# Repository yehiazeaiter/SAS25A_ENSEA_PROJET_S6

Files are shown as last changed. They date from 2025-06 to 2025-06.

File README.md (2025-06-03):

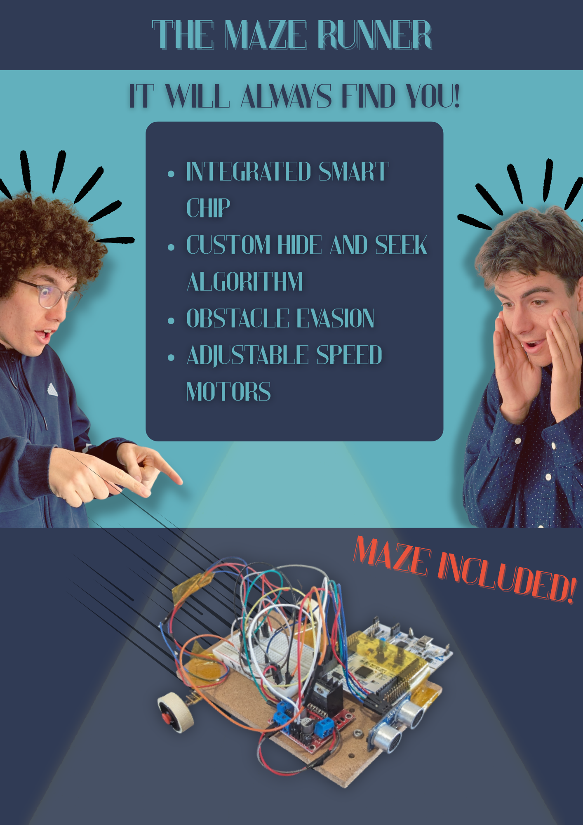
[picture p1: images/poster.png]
Project Poster


# SAS25A_ENSEA_PROJET_S6

This repository contains the code and documentation for our first year school project. An embedded systems project using STM32CubeIDE to build a robot that plays hide and seek in a labyrinth using motors for moving, an ultrasonic sensor for obstacle detection, and an infrared sensor for detecting the other playing robot.

## Table of Contents
- [Project Overview](#project-overview)
- [Team Members](#team-members)
- [Folder Structure](#folder-structure)

## Project Overview

This embedded systems project aimed to build a robot capable of playing a game of hide-and-seek using sensors and motor control, based on the STM32L476RG microcontroller, in a compact design with an integrated PCB.

### What We Achieved
- The robot can **move forward** using DC motors
- It **stops automatically** when an obstacle is detected via the ultrasonic sensor
- It **blinks an LED** when receiving a signal from the infrared receiver
- A PCB design ready to print

### What Was Not Fully Implemented
- Autonomous hide-and-seek behavior
- Navigation or decision-making logic
- Compact design with an integrated PCB

Despite not reaching the original goal, the project successfully integrates core embedded system concepts such as motor control, sensor interfacing, and interrupt-based signaling.

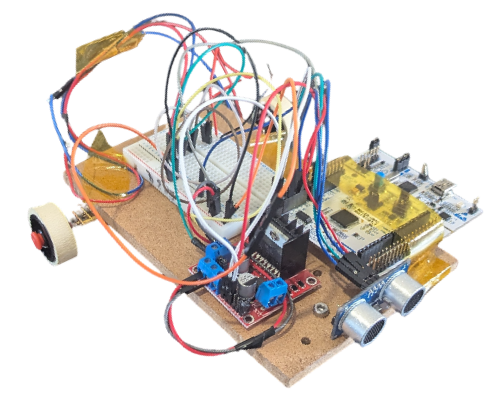
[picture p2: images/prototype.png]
Project Prototype


## Team Members

- BELLAHBIB Amate-Allah 
- EL MESTARI Mohamed-Amine 
- NASSCHAERT Florent 
- PERRIN Maël 
- ZEAITER Yehia 

### Contributions

| Member | Contributions Summary | 
|---|---|
| Amate-Allah  | PCB design, infrared sensor testing, final presentation, final report |
| Mohamed-Amine| Ultrasonic sensor testing, weekly reports, final report |
| Florent | Infrared sensor testing, programming, timer setup, algorithm diagram |
| Maël | Stepper motors testing, 3D modeling, GANTT diagram |
| Yehia | Ultrasonic sensor testing, DC and stepper motors testing, timer setup, SADT diagram, task distribution  |

## Folder structure
- `project files/`: KiCad and STM32CubeIDE project files
- `how to guides/`: guides on how to achieve the different tasks done in the project

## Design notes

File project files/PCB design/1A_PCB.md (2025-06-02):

## This folder contains all the files related to the PCB design

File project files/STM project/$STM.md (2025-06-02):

## This folder contains the STM project that was used to run the prototype

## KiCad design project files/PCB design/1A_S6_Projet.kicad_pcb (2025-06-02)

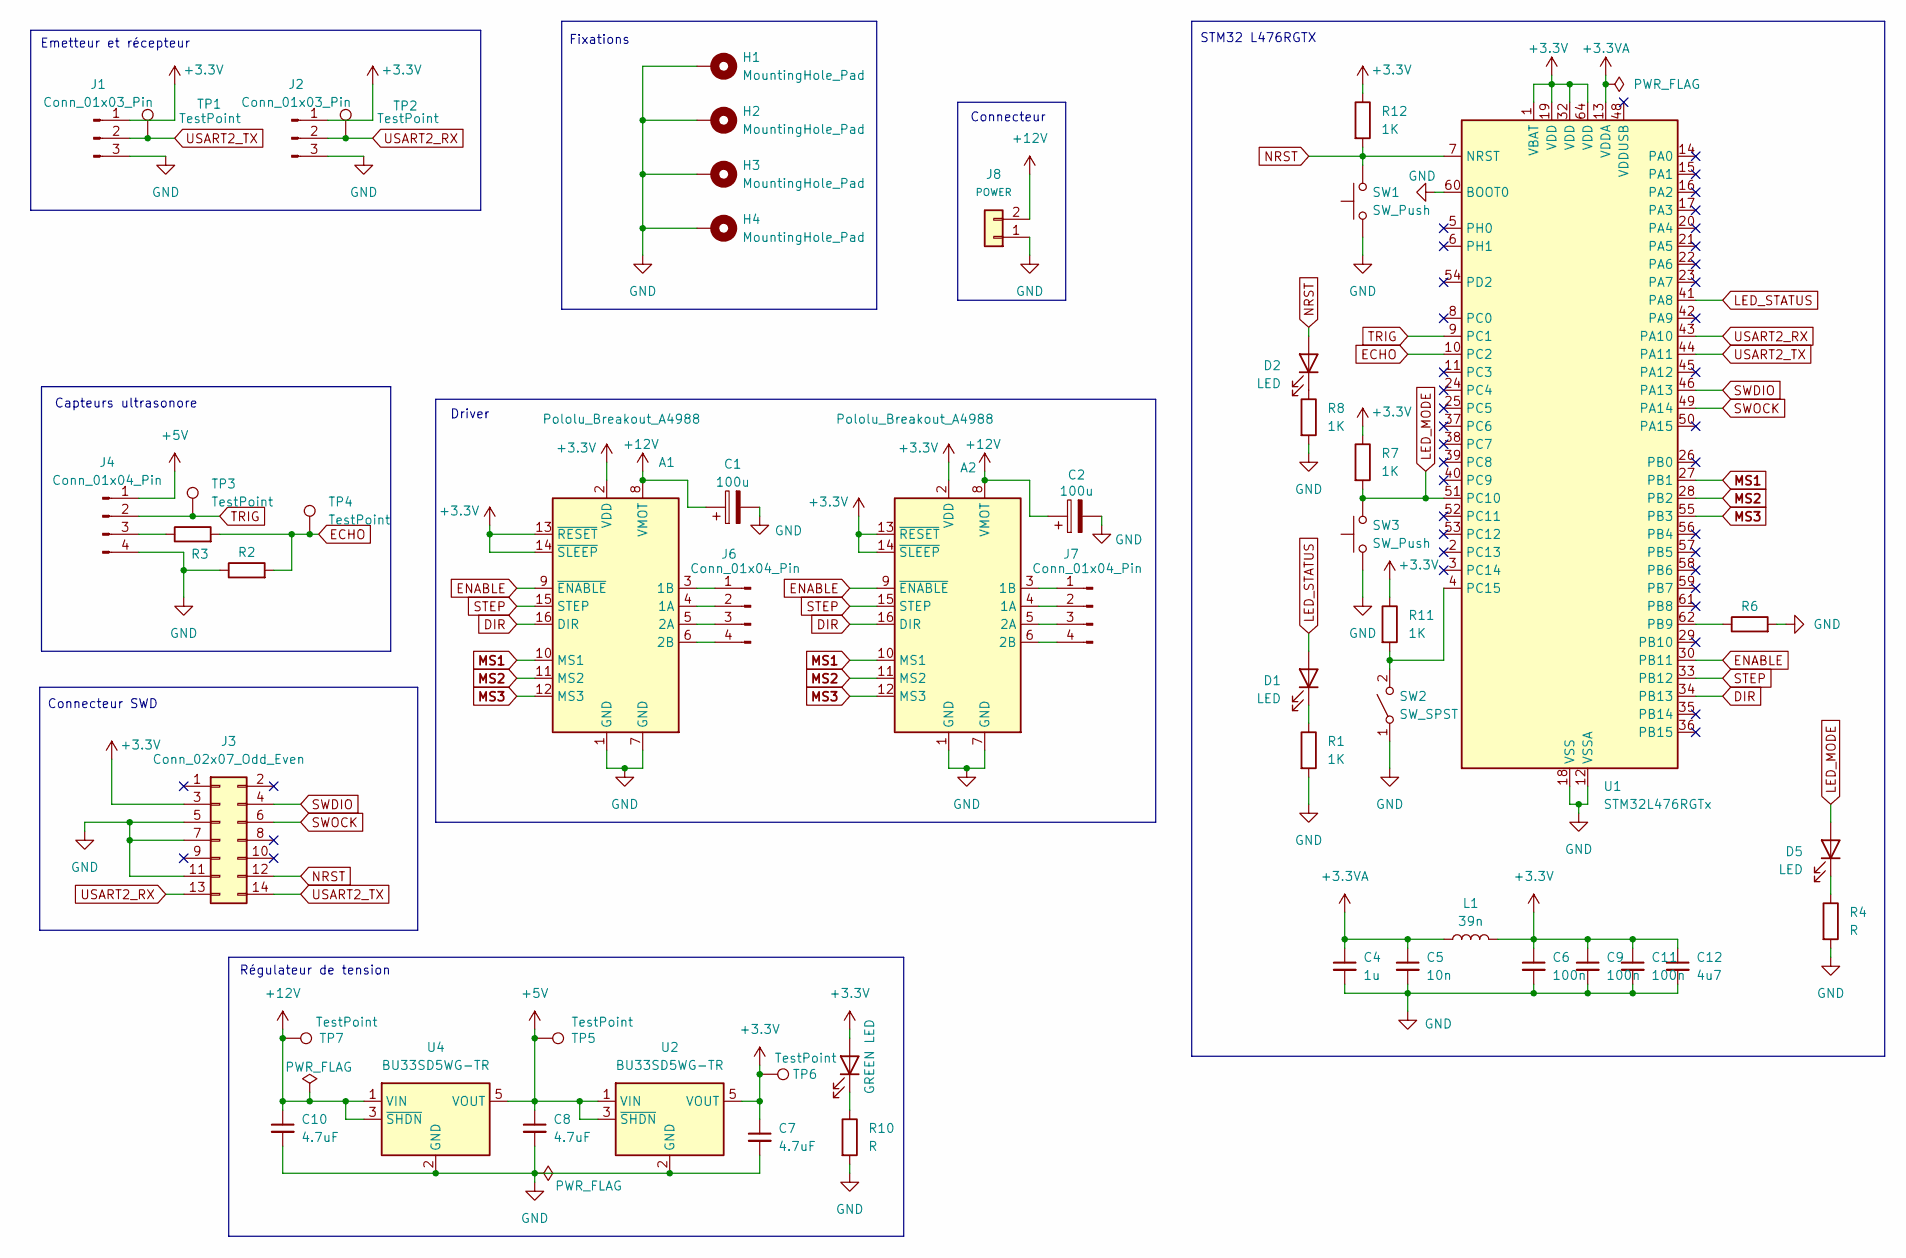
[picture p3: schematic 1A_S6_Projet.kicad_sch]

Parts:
A1, A2: Pololu_Breakout_A4988; Pololu_Breakout-16_15.2x20.3mm
C1, C2: 100u; CP_Elec_8x10.5
C4: 1u; C_1206_3216Metric_Pad1.33x1.80mm_HandSolder
C5: 10n; C_0805_2012Metric_Pad1.18x1.45mm_HandSolder
C6, C9, C11: 100n; C_1206_3216Metric_Pad1.33x1.80mm_HandSolder
C7, C8, C10: 4.7uF; C_1206_3216Metric_Pad1.33x1.80mm_HandSolder
C12: 4u7; C_1206_3216Metric_Pad1.33x1.80mm_HandSolder
D1, D2, D5: LED; LED_0603_1608Metric_Pad1.05x0.95mm_HandSolder
D4: GREEN LED; LED_0603_1608Metric_Pad1.05x0.95mm_HandSolder
H1, H2, H3, H4: MountingHole_Pad; MountingHole_3.2mm_M3_DIN965_Pad
J1, J2: Conn_01x03_Pin; JST_XH_B3B-XH-A_1x03_P2.50mm_Vertical
J3: Conn_02x07_Odd_Even; PinHeader_2x07_P1.27mm_Vertical_SMD
J4, J6, J7: Conn_01x04_Pin; JST_XH_B4B-XH-A_1x04_P2.50mm_Vertical
J8: POWER; JST_XH_B2B-XH-A_1x02_P2.50mm_Vertical
L1: 39n; L_0805_2012Metric_Pad1.05x1.20mm_HandSolder
R1, R3, R6, R7, R8, R11, R12: 1K; R_0603_1608Metric_Pad0.98x0.95mm_HandSolder
R2: 2K; R_0603_1608Metric_Pad0.98x0.95mm_HandSolder
R4, R10: R; R_0603_1608Metric_Pad0.98x0.95mm_HandSolder
SW1, SW3: SW_Push; SW_Push_1P1T_NO_CK_KMR2
SW2: SW_SPST; SW_Push_1P1T_NO_CK_KMR2
TP1, TP2, TP3, TP4, TP5, TP6, TP7: TestPoint; TestPoint_Pad_D1.0mm
U1: STM32L476RGTx; LQFP-64_10x10mm_P0.5mm
U2, U4: BU33SD5WG-TR; SOT-23-5

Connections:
+3.3V: A1.2 (VDD), A1.13 (~RESET), A1.14 (~SLEEP), A2.2 (VDD), A2.13 (~RESET), A2.14 (~SLEEP), C6.1, C7.1, C9.1, C11.1, C12.1, D4.2 (A), J1.1, J2.1, J3.3, L1.2, R7.1, R11.1, R12.1, TP6.1, U1.1 (VBAT), U1.19 (VDD), U1.32 (VDD), U1.64 (VDD), U2.5 (VOUT)
+3.3VA: C4.1, C5.1, L1.1, U1.13 (VDDA)
+5V: C8.1, J4.1, TP5.1, U2.1 (VIN), U2.3 (~SHDN), U4.5 (VOUT)
+12V: A1.8 (VMOT), A2.8 (VMOT), C1.1, C2.1, C10.1, J8.2, TP7.1, U4.1 (VIN), U4.3 (~SHDN)
DIR: A1.16 (DIR), A2.16 (DIR), U1.34 (PB13)
ECHO: R2.2, R3.2, TP4.1, U1.10 (PC2)
ENABLE: A1.9 (~ENABLE), A2.9 (~ENABLE), U1.30 (PB11)
GND: A1.1 (GND), A1.7 (GND), A2.1 (GND), A2.7 (GND), C1.2, C2.2, C4.2, C5.2, C6.2, C7.2, C8.2, C9.2, C10.2, C11.2, C12.2, H1.1, H2.1, H3.1, H4.1, J1.3, J2.3, J3.5, J3.7, J3.11, J4.4, J8.1, R1.2, R2.1, R4.2, R6.2, R8.2, R10.2, SW1.1, SW2.1 (A), SW3.1, U1.12 (VSSA), U1.18 (VSS), U1.31 (VSS), U1.47 (VSS), U1.60 (BOOT0), U1.63 (VSS), U2.2 (GND), U4.2 (GND)
LED_MODE: D5.2 (A), R7.2, SW3.2, U1.51 (PC10)
LED_STATUS: D1.2 (A), U1.41 (PA8)
MS1: A1.10 (MS1), A2.10 (MS1), U1.27 (PB1)
MS2: A1.11 (MS2), A2.11 (MS2), U1.28 (PB2)
MS3: A1.12 (MS3), A2.12 (MS3), U1.55 (PB3)
NRST: D2.2 (A), J3.12, R12.2, SW1.2, U1.7 (NRST)
unnamed: A1.4 (1A), J6.2
unnamed: A1.3 (1B), J6.1
unnamed: A1.5 (2A), J6.3
unnamed: A1.6 (2B), J6.4
unnamed: A2.4 (1A), J7.2
unnamed: A2.3 (1B), J7.1
unnamed: A2.5 (2A), J7.3
unnamed: A2.6 (2B), J7.4
unnamed: D1.1 (K), R1.1
unnamed: D2.1 (K), R8.1
unnamed: D4.1 (K), R10.1
unnamed: D5.1 (K), R4.1
unnamed: J4.3, R3.1
unnamed: R11.2, SW2.2 (B), U1.4 (PC15)
unnamed: R6.1, U1.62 (PB9)
STEP: A1.15 (STEP), A2.15 (STEP), U1.33 (PB12)
SWDIO: J3.4, U1.46 (PA13)
SWOCK: J3.6, U1.49 (PA14)
TRIG: J4.2, TP3.1, U1.9 (PC1)
USART2_RX: J2.2, J3.13, TP2.1, U1.43 (PA10)
USART2_TX: J1.2, J3.14, TP1.1, U1.44 (PA11)

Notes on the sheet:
Capteurs ultrasonore
STM32 L476RGTX
Fixations
Régulateur de tension
Connecteur
Connecteur SWD
Driver
Emetteur et récepteur

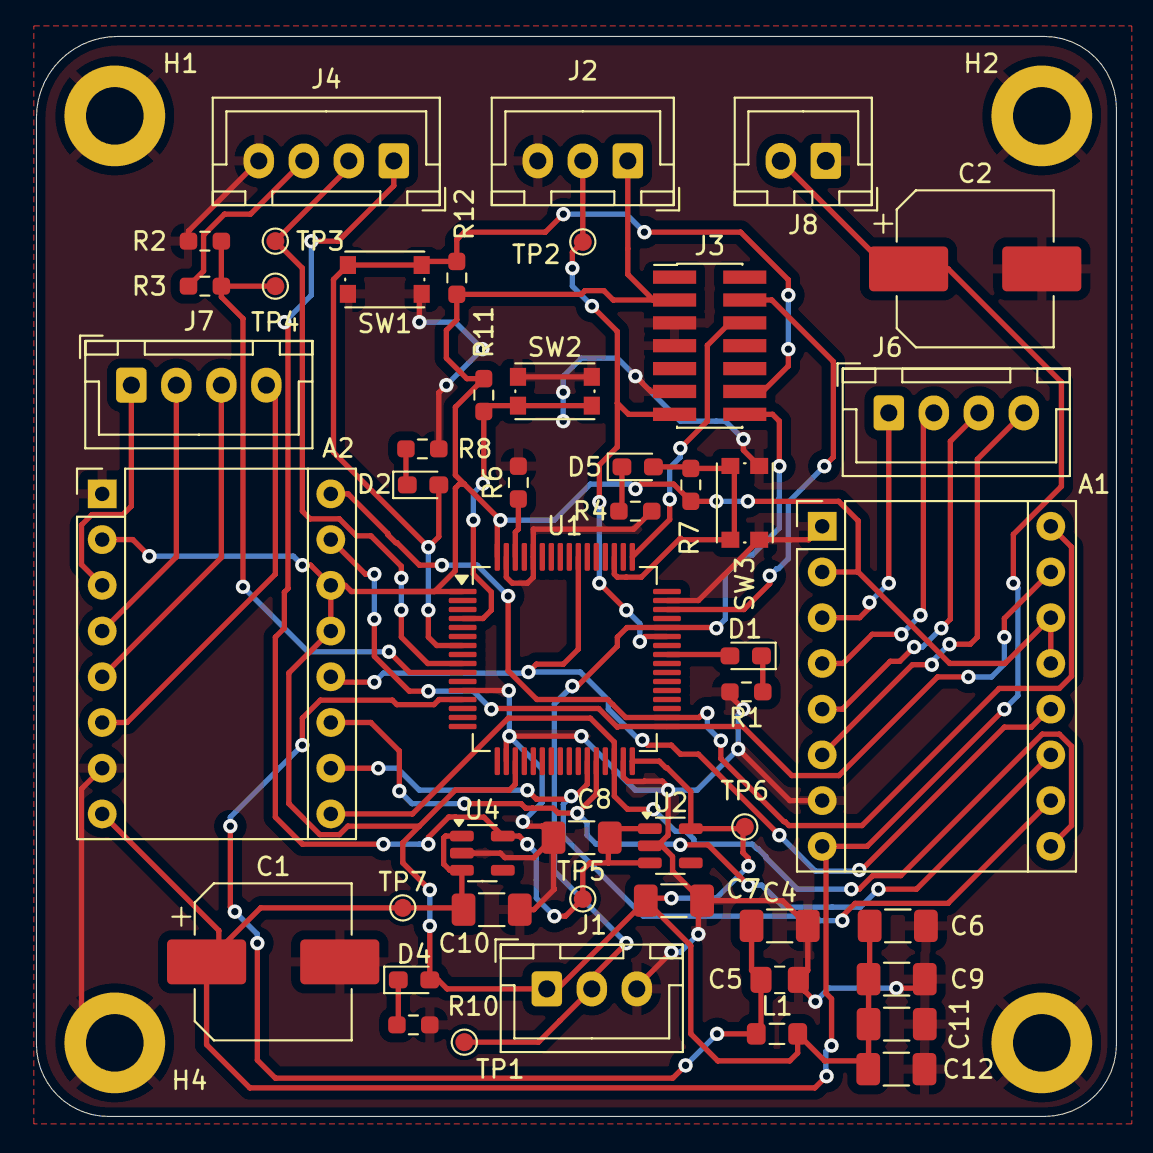
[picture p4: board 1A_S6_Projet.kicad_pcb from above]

Board: 2 copper layers, 60.0 x 60.0 mm, 52 parts (0 on the bottom side), 35 nets.

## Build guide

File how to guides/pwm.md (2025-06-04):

# Quick guide to generate a PWM signal with an ST microcontroller

## What is it? 
PWM stands for Pulse-width modulation, which is any method of representing a signal as a rectangular wave with a varying duty cycle. So a PWM signal is simply a rectengular wave with a varying duty cycle.
PWM signals

*Representation of a PWM signal with different duty cycles*

## Its uses
PWM is mainly used to get **analog like** results with a digital signal, and by digital signal, we mean a signal that switches between two values : 
- LOW which corresponds to 0 V
- HIGH which corresponds to a positive value, commonly 3.3 V or 5 V for microcontrollers

PWM is therefore useful for controlling the average power or or effective voltage delivered by an electrical signal. The higher the duty cycle is, the higher the average is. This is useful in applications like controlling LED brightness, DC motor speed, servo position, heating elements, and more.

The frequency of the signal is also important, it should be chosen correctly so that the electronic device is not negatively affected by the constant ON and OFF switching of the signal.

For example, if you use a PWM signal with a frequency of 10 Hz to control an LED’s brightness, the LED will appear to blink because the human eye can detect such slow flickering. However, if the frequency is increased to 1000 Hz or more, and the duty cycle is 50%, the LED will appear to emit a steady light at reduced brightness due to the eye's persistence of vision.

On the other hand, a motor, being electromechanical, cannot react instantly to rapid changes in the signal, due to inductance and inertia, so when choosing a PWM signal with a high enough frequency, the motor effectively responds to the average power of the PWM signal, rather than each individual pulse. 
Essentially, the frequency should be high enough so that the motor is not able to keep up with the signal fluctuations, otherwise there will be jitters in the movement. 

These two examples were given to explain that we see similar results (smooth output) in different devices, but they're due to different reasons, which is always good to keep in mind.

That being said, a frequency shouldn't be too high for the component either to avoid possible power dissipation and heating problems.
Always refer to the component's datasheet or technical specifications to have the correct frequency range.

## Generating a PWM signal with a microcontroller
For our example, we'll be using STML476RG, but this method shouldn't be very different across different ST microcontrollers.

PWM generation is pretty forward, it is done using timers, in our example, we chose the timer TIM5.
This timer can generate PWM signals in 4 channels, we'll choose channel 2. Do not forget to check the internal clock box.

There are three main parameters affecting our signal, PSC and ARR to choose its frequency, and the Pulse parameter decides the value of the duty cycle.
Our main clock speed is at 80 MHz, we choose PSC = 79 and ARR = 999 to have a timer frequency of 1 kHz.

The Pulse value basically refers the number of timer counts the output stays HIGH within each PWM cycle, therefore, it should be chosen relatively to the ARR value.
For example, to have a 50% duty cycle, we set Pulse to 500.
tim5 settings

*Screenshot of the TIM5 configuration*

As you can see in the parameters, there are different PWM modes to choose from, for a normal PWM signal, we choose Mode 1. It simply means that the output is HIGH when the timer counter is less than the Pulse value, and LOW when it's equal or greater, so the signal starts by being HIGH then switches to LOW.

Now that the timer is set, we can configure different pins to recieve this signal. For example, we choose PA1 :


Save the ioc file so that the IDE apply your configuration. Now you just need to start TIM5 and its PWM generation in the main.c file, in the `main()` function, after the initializations (in the  /* USER CODE BEGIN 2 */ for our case). 
```c
  HAL_TIM_Base_Start_IT(&htim5);
  HAL_TIM_PWM_Start(&htim5, TIM_CHANNEL_2);
```

If you want to change the ARR value (to control the frequency) or the Pulse value (to control the duty cycle) at any moment in the code, you can use the functions `__HAL_TIM_SET_AUTORELOAD(__HANDLE__, __AUTORELOAD__)` and `__HAL_TIM_SET_COMPARE(__HANDLE__, __CHANNEL__, __COMPARE__)`, in our case, the syntax would be :
```c
__HAL_TIM_SET_AUTORELOAD(&htim5, new_arr);               //used to change the ARR value
__HAL_TIM_SET_COMPARE(&htim5, TIM_CHANNEL_2, new_pulse); //used to change the Pulse value
```
And that's it!

Now you can visualise this signal on an oscilloscope, or try to dynamically change the brightness of a LED if you want a first easy application.
Enjoy!

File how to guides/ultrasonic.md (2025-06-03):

# Guide to setup and use the ultrasonic sensor HC-SR04 with STM32CubeIDE

## What it is for
This module is used to measure distances between 3 cm and 2 meters (otherwise it loses accuracy)

## Constitution
The HC-SR04 ultrasonic module is equiped with two main parts, an ultrasonic transmitter, and an ultrasonic receiver. It contains 4 pins : 
- 5V pin to power the module
- Trigger pin to control the transmitter
- Echo pin to read the receiver
- GND pin

Ultrasonic sensor

## How it works
The ultrasonic transmitter sends periodic 8 cycle bursts of ultrasound at 40 kHz with boosted echo. Upon detecting an object, these waves are reflected towards the receiver. Therefore, the time it takes for these waves to travel to the object forth and back is used to calculate the distance.

Ultrasonic waves

*Image credit : teachwithict*

## Visualization 
In order to write the necessary STM code to correctly use this module, we have to understand what we should code precisely.
There are mainly two things :
- Pulse generation with the transmitter
- Reading the echoed signal with the receiver

According to the datasheet, the trigger needs to be supplied by 10 μs pulses and then the transmitter will send out
an 8 cycle burst of ultrasound at 40 kHz and raise its echo. The pulses sent to the Trigger pin should look like this:

pulses

zoomed in pulse

The signal read on the Echo pin looks like the following :

echo

In fact, the Echo signal stays on HIGH level until it receives the ultrasonic wave echo. Therefore, in order to calculate distance with its input, we should calculate the distance an ultrasonic wave travels during the time where it stays high, divided by two, because the wave travels the distance to the object back and forth.

In the following sections, we'll see how to do the right setup to finally calculate distance.

## Pin setup
- 5V pin should be connected to a 5V power supply (can be drawn from the STM)
- Trigger pin should be connected to the STM in GPIO Output mode
- Echo pin should be connected to the STM in GPIO_EXTI mode (will be explained later)
- The GND pin should be connected to the GND node of the circuit

## Pulse generation
In order to generate pulses, we are going to use some STM timer action. We need pulses with 10 μs width, we'll choose a periodicity of 200 ms in able to safely calculate distances up to 20 meters (you can do the maths yourself!). 
To generate these pulses, we will set a timer that creates interrupts every 10 μs. For our example, we're using an STML476RG microcontroller which has a core clock speed of 80 MHz, we choose to use the timer TIM2 for this mission. Go to the ioc configuration file and set the following values in the TIM2 section :
- Set the Clock Source to Internal Clock
- Set the PSC to 79
- Set the ARR to 9
  
  *These PSC and ARR values are to be adjusted to your core clock speed*

  Save the ioc file and the necessary initialisation code will be generated by the IDE.

TIM2 config

*Screenshot of the timer TIM2 settings*

After setting up the timer, we should enable its interrupts, in the ioc file you go to Pinout&Confiration -> System Core -> NVIC and you check the TIM2 global interrupt box :



*Screenshot of the NVIC settings*

Now that the timer is set up, we can start generating the pulses, a pulse is simply a high level between two interruptions, every 200 ms. 
Therefore, the code is very simple, in the stm32*_it.c file (stm32l4xx_it.c in our example), you should find a function with the `void TIM2_IRQHandler(void)` prototype, this function is called every time the timer creates an interrupt, therefore every 10 μs. In 200 ms, there are 20.000 intervals of 10 μs width, that's why we define a constant called Trigger_Period = 20000.
During the first one of these intervals, we want the signal sent to the Trigger pin to be set as HIGH, during the remaining intervals, we want it set to low, therefore comes the following code : 

```c
  void TIM2_IRQHandler(void)
{
  /* USER CODE BEGIN TIM2_IRQn 0 */
	if (trigger_counter == Trigger_Period - 1){               // Trigger_Period = 20000
			HAL_GPIO_WritePin(Trigger_Port, Trigger_PIN, SET);
	}
	else if (trigger_counter == Trigger_Period){
		HAL_GPIO_WritePin(Trigger_Port, Trigger_PIN, RESET);
		trigger_counter = 0;
	}

	trigger_counter += 1;

  /* USER CODE END TIM2_IRQn 0 */
  HAL_TIM_IRQHandler(&htim2);
  /* USER CODE BEGIN TIM2_IRQn 1 */

  /* USER CODE END TIM2_IRQn 1 */
}
 ```

What's left is to start the timer after its initialization in the main.c file, you simply write HAL_TIM_Base_Start_IT(&htim2); in the USER BEGIN CODE 2 section of the main function.

You can visualise the output of the Trigger pin on the oscilloscope to verify that the pulse generation is correct.

## Distance calculation
The distance calculation is done through the measuring of the time interval between sending the ultrasonic signal and receiving it back. Once the sonic burst is launched from the module, the Echo pin goes to HIGH state, and once it receives the signal back, it goes back to LOW state, as visualised before.
So in order to calculate the distance, we have to detect this HIGH level using our microcontroller. A simple yet effective way to do it, is to detect the rising edge of the signal, and its falling edge, and calculating the time between them.
Fortunately, the ST microcontroller comes with edge detection features. We mentioned earlier that the Echo pin should be configured in EXTI mode, this is because this mode allows the pin to do interruptions when certain events occur, EXTI actually stands for "external interrupt". In our case, we want interrupts to happen when a rising or a falling edge is detected, in order to check time on each of these instances. 
For our example, we configure the ECHO pin in GPIO_EXTI1 mode. Now we should configure the EXTI behavior. 
Go to the ioc file, Pinout&Confiration -> System Core -> GPIO and select the EXTI pin, select the External Interrupt with Rising/Falling edge triger detection option, make sure that the GPIO Pull-up/Pull-down is set to no.

echo pin

*Screenshot of the GPIO settings*

For measuring time, the calssic `HAL_GetTick()` function won't do the trick in our case, because it has a precision of 1 ms, and sounds travel around 35 cm in 1 ms! So it will generate a great imprecision when calculating distances.
Instead, we'll set up a timer for getting the exact time on two instants : rising edge and falling edge.
For our example, we set TIM1 with a high ARR value for high precision, and to have a time interval large enough to cover distances around 20 m, here is our configuration :

timer echo

Now we get to coding, we create two functions, one for handling the rising edge, it simply tracks the moment the rising edge occured, and the other function is for handling the falling edge, it tracks the moment the falling edge occured and it calculates the distance. 
You might have already figured out that the use of the timer can cause the second time to be lower than the first time because of the timer reset, that's why we use the ternary expression displayed in the code, it corrects the time shift. The high ARR value assures that the start time won't need to be shifted by more than one period.

```c
uint32_t time_start = 0;
uint32_t time_end = 0;
float distance_cm = 0.0f;
extern TIM_HandleTypeDef htim1;

// to track instants, we use the counting of timer 1
void handle_rising_edge(void)
{
    time_start = __HAL_TIM_GET_COUNTER(&htim1);   // tracking of the instant of the rising edge
}

void handle_falling_edge(void)
{
    time_end = __HAL_TIM_GET_COUNTER(&htim1);    // tracking of the instant of the falling edge

    uint32_t duration = (time_end >= time_start) ?
                        (time_end - time_start) :
                        ((0xFFFF - time_start) + time_end);  // the ternary expression assuring the right time calculation
    // speed of an ultrasonic wave in the air ≈ 343 m/s = 0.0343 cm/µs
    // the wave travels the distance back and forth - division by 2
    distance_cm = ((float)duration * 0.0343f) / 2.0f;
}
```

Finally these functions should be called upon interruptions, in the `stm32*_it.c` or the `main.c` file, call them in the EXTI Callback function (you may need to define this function by yourself), according to the signal state.

```c
void HAL_GPIO_EXTI_Callback(uint16_t GPIO_Pin) {
	 if (GPIO_Pin == Echo_PIN)
	    {
	        if (HAL_GPIO_ReadPin(Echo_Port, Echo_PIN) == GPIO_PIN_SET)
	        {
	            handle_rising_edge();

	        }

	        else
	        {
	            handle_falling_edge();
	        }
	    }

}
```

## Use 
As you may have noticed, the constantly update variable "distance_cm" is declared as global, therefore you can use it anywhere in the project, you should simply call it in the .c file you're going to use it in, by typing `extern float distance_cm;` .

I suggest you try to apply that by writing a simple code that makes a LED light up when an object is detected at 10 cm.
Otherwise you can try to print the constantly updated values of the distance in a terminal.

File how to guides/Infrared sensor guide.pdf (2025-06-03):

## Guide pas-à-pas pour la communication infrarouge (émetteur et récepteur )

### 1. Objectif du système

La communication infrarouge a pour but d’assurer une liaison simple entre les deux robots. Plus précisément, dans le cadre du jeu de cache-cache, le robot qui se cache utilise un émetteur infrarouge pour diffuser un signal, tandis que le robot chercheur est équipé d’un récepteur infrarouge lui permettant de détecter la présence du robot caché.

### 2. Composants utilisés

Pour établir la communication infrarouge entre les deux robots, nous avons utilisé des modules de la gamme Grove.

Émetteur infrarouge

- Nom du module : Grove – Infrared Emitter v1.2
- Description : Ce module contient une LED infrarouge capable d’émettre un signal infrarouge. Il est conçu pour fonctionner sous une tension de 5V et se commande via une broche numérique du microcontrôleur.
- lien : https://wiki.seeedstudio.com/Grove-Infrared_Emitter/

Récepteur infrarouge

- Nom du module : Grove – Infrared Receiver v1.0
- Description : Ce module est équipé d’un capteur infrarouge capable de détecter un signal IR provenant de l’émetteur. Il délivre un signal logique en sortie, interprétable par le microcontrôleur pour déterminer la réception d’un signal.
- lien : https://wiki.seeedstudio.com/Grove-Infrared_Emitter/

### 3. Branchement utilisé

Émetteur infrarouge

STM32-L476RG | Grove - Infrared Emitter
5V | Red
GND | Black
Not connected | White
D2 | Yellow

Récepteur infrarouge

STM32-L476RG | Grove - Infrared Emitter
5V | Red
GND | Black
Not connected | White
D4 | Yellow

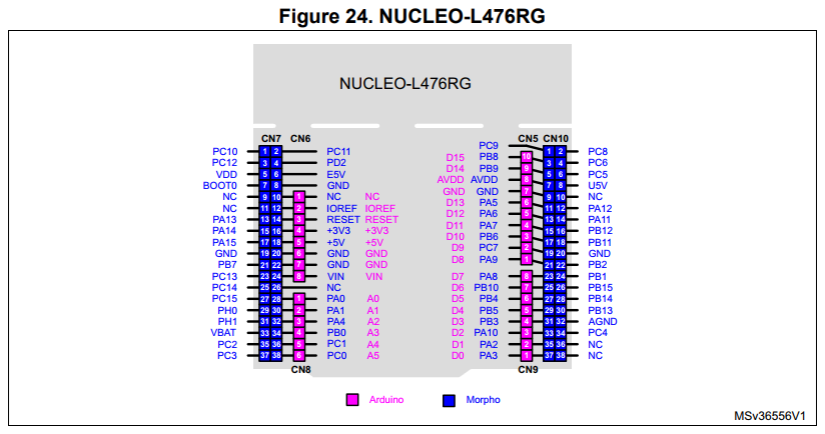
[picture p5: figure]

Nucleo-L476RG pin mapping

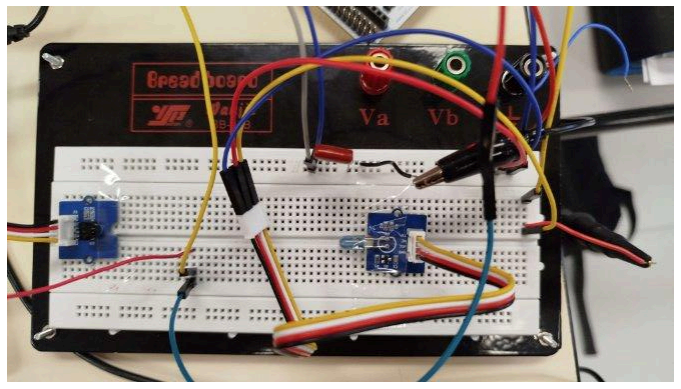
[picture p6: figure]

Récepteur et émetteur mis en face pour assurer le bon fonctionnement

### 4. Principe de fonctionnement

Du côté émetteur, un signal créneaux (succession d’états hauts et bas) est généré via la broche numérique choisie du microcontrôleur pour allumer et éteindre la LED infrarouge à une fréquence régulière.

Du côté récepteur, ce signal est interprété électriquement : à chaque front montant envoyé par l’émetteur, le récepteur réagit en produisant un front descendant.

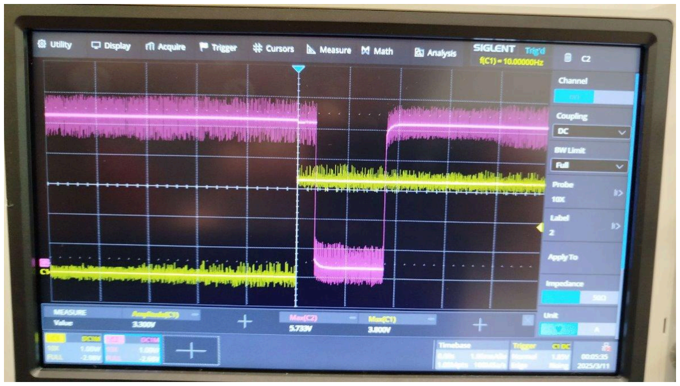
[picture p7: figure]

Observation experimentale à l’osscilloscope de la réaction du récepteur (rose) au signal de l’émetteur (jaune)

### 5. Gestion logicielle - Le timer

Afin de gérer la communication infrarouge en parallèle des déplacements du robot, nous avons mis en place un timer. L’objectif principal de ce timer est de permettre l’émission ou la lecture de signaux infrarouges sans bloquer le reste du programme. Le timer fonctionne en arrière-plan et déclenche régulièrement une routine permettant :

- D’envoyer un signal IR, ou
- De vérifier l’état du récepteur IR, ou
- D’agir en fonction de la lecture du récepteur

Activation du timer (choix arbitraire)

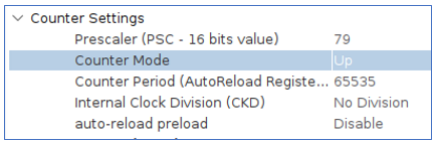
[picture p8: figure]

Paramètre du timer
Vous trouverez la démarche dans le tp ou dans le document Developer's guide for STM32CubeIDE v31 12/03/2025 (https://moodle.ensea.fr/mod/resource/view.php?id=4795) à la section 8.2.

### 6. Implémentation des capteurs

La broche de l’émetteur est configurée en mode output et celle du récepteur en mode input. À noter que le choix des broches est arbitraire.

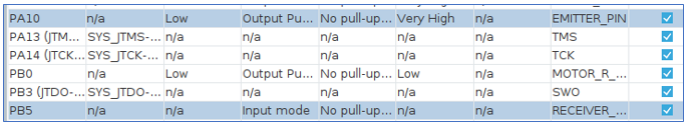
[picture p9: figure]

Activation des broches dans le bon mode

Puis pour le code on définit des macros qui permettent de pas mettre de valeur magique.

Définition d’une macro pour l'émetteur

Définition d’une macro pour le récepteur

### 7. Exemple de code

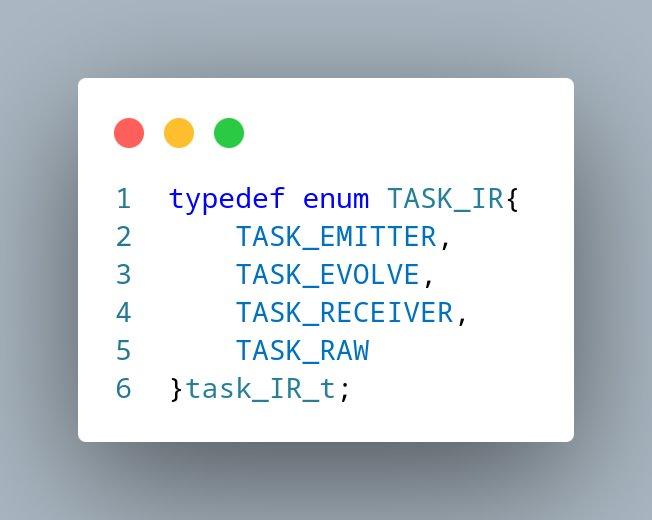
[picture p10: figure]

Utilisation d’un type énuméré pour différencier les différentes tâche à réaliser (TASK_RAW sert à faire un modulo, et permet donc d’ajouter des tâches si besoin est)

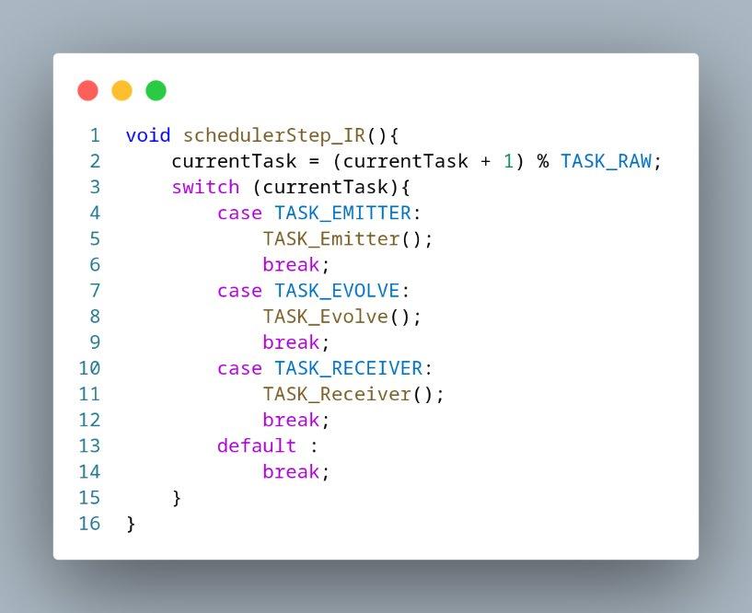
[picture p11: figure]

Utilisation d’un scheduler avec un switch, les fonctions appelées sont définis dans un autre fichier. Vous pouvez choisir ce qu’elle font

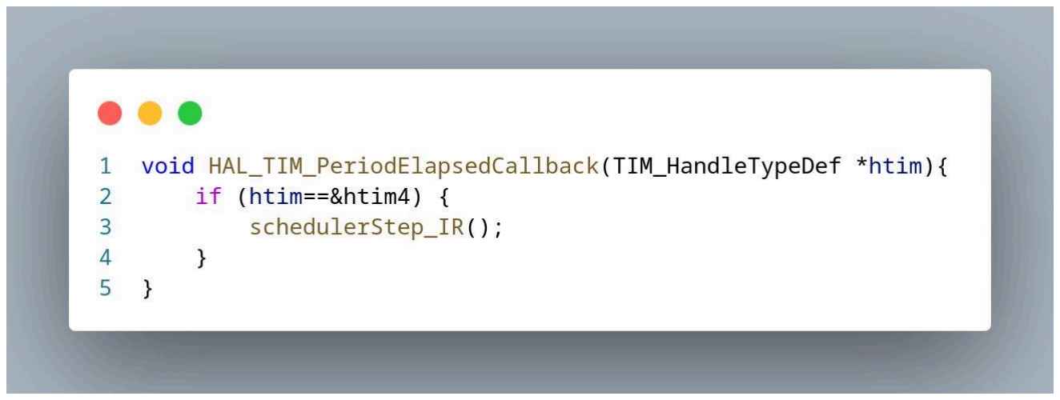
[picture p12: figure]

C’est une fonction que l’on réécrit (attribut weak) pour appeler le scheduler lorsque notre timer (timer 4) fait une interruption.

Code de TASK_Emitter, qui permet de faire clignoter la led

Code de TASK_Receiver, qui interroge le récepteur si jamais il a été activé. Pour le code de GetActivate référez vous au tp avec le bouton.

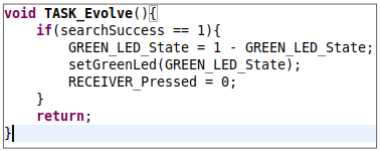
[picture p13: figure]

Ici c’est un exemple de code pour TASK_Evolve, la led clignote si l’autre robot à été trouvé.

### 8. Conseil pratique

Pour éviter les erreurs et maximiser l’efficacité, voici quelques recommandations issues de notre expérience :

- Vérifiez soigneusement vos branchements : assurez-vous que chaque fil est connecté à la bonne broche (VCC, GND, signal).
- Paramétrez correctement l’IOC : une erreur arrive vite ici
- Écrivez un code lisible et commenté : cela facilite la compréhension pour les autres et lors des sessions suivantes et surtout limite les oublis.
- Alignez bien les capteurs : pour une détection fiable, l’émetteur et le récepteur doivent être à la même hauteur et placés en face l’un de l’autre.la LED infrarouge émet dans un cône d’environ ±17°, donc un mauvais alignement réduit fortement la portée du signal.

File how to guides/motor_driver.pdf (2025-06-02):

## How To : Tester un moteur pas à pas avec A4988 et STM32 Nucleo-L476RG

### 1. Objectif

Expliquer comment connecter et contrôler un moteur pas à pas bipolaire à l’aide d’un driver A4988 et d’un microcontrôleur STM32 (Nucleo-L476RG).

### 2. Matériel nécessaire

- Carte STM32 Nucleo-L476RG
- Driver A4988
- Moteur pas à pas bipolaire (ex: 11HS18-0674S, 0.67 A)
- Alimentation externe pour le moteur (ex: 12V)
- Condensateur 100 µF (entre VMOT et GND du driver)

### 3. Branchement

Voici les différentes documentations pour les branchements du driver et du moteur

Ce moteur bipolaire a deux bobines :

Bobine 1 :

A+ → Fil noir (BLK)
A- → Fil vert (GRN)

Bobine 2 :

B+ → Fil rouge (RED)
B- → Fil bleu (BLU)

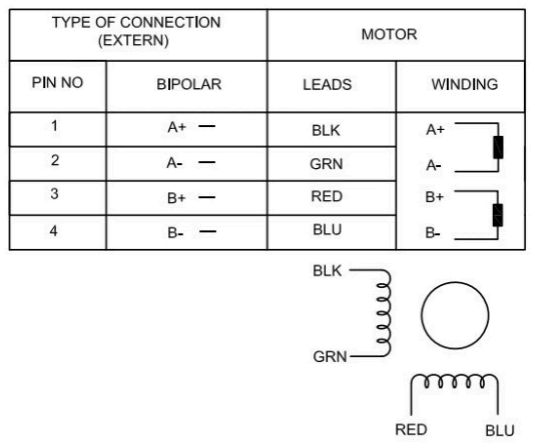
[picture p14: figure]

Ces bobines doivent être alimentées par le driver avec des signaux électriques appropriés pour faire tourner le moteur.

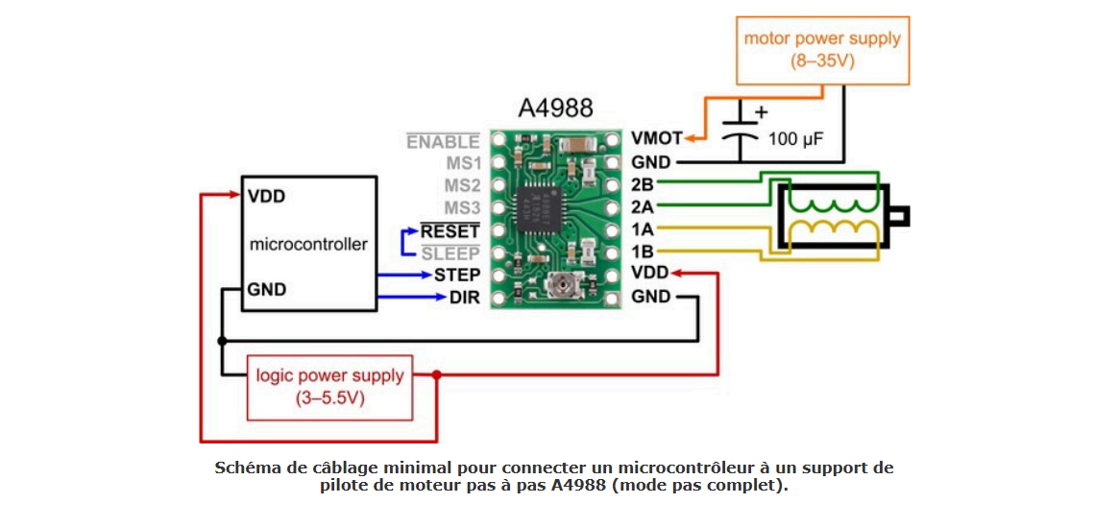
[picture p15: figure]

Détails des branchements :

STEP : PA0
DIR : PA1
VMOT : +12V (alimentation moteur)
VDD : 3.3V (STM32)
Moteur : 4 fils connectés aux 1A/1B/2A/2B selon datasheet

Ajouter un condensateur 100 µF entre VMOT et GND du driver avant d’alimenter !

### 4. Réglage du courant sur le driver A4988

Le moteur supporte 0.67 A → on ajuste le potentiomètre du A4988 pour Vref ≈ 0.54 V

Vref=Imot×0.8=0.67×0.8≈0.54V

Ainsi, on alimente le driver (VMOT et VDD) et avec un multimètre (sonde noire sur GND, sonde rouge sur la vis du potentiomètre) on tourne jusqu’à 0.54 V.

### 5. Code STM32

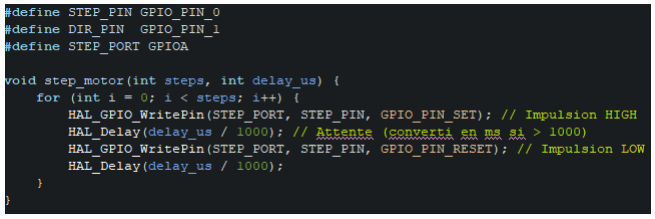
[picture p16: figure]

### 6. Conclusion

En suivant cette procédure, le moteur pas à pas est contrôlé de manière fluide avec un timer hardware.

Le bon réglage du courant et la précision des signaux sont essentiels pour éviter les erreurs.

Le condensateur a un rôle important, il permet de stabiliser la tension et protège aussi le driver. Ainsi, il faut toujours l’installer avant d’alimenter un driver de moteur pas à pas !

Pour la génération d'un pwm avec un timer, celle-ci est expliquée dans un autre guide.
